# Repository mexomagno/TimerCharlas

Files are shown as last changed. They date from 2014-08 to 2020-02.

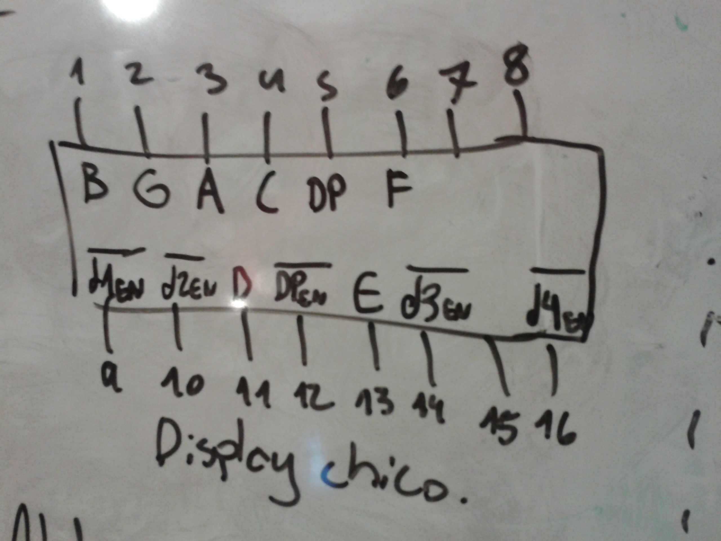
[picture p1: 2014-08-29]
Hardware/Componentes/camera/IMG_20140820_162948.jpg

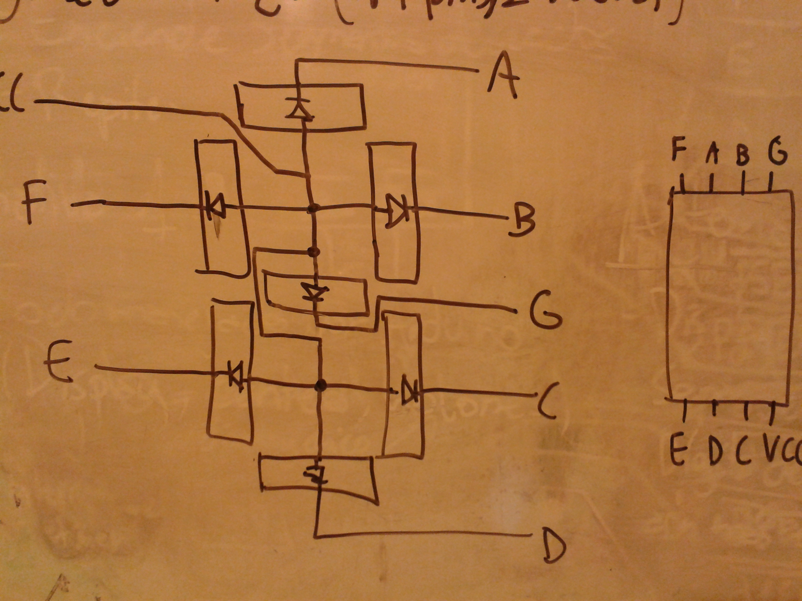
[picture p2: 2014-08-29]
Hardware/Componentes/camera/IMG_20140820_185731.jpg

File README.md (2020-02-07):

Timer para Charlas
============

<h3>Display de cuenta regresiva para charlas y presentaciones.</h3>
<p>Al momento de dar una charla, exponer en un seminario, hablar ante audiencias con tiempo limitado, llevar la cuenta del tiempo restante es esencial. Cuando el escenario es grande o es necesario moverse, es cómodo poder enterarse de cuánto tiempo queda a través de un estímulo visual.</p>
<p>El timer de charlas pretende ser un apoyo para las personas que tengan esta necesidad particular, y que no consideren suficientes las aplicaciones de tablets destinadas a este mismo fin, donde el tamaño del display depende del tamaño del tablet, además de ser poco discreto poner un tablet en el suelo.</p>
Este es un proyecto personal que no busca ser nada grande. Se dio por dos cosas:
<ol>
<li>Mi madre quería reemplazar un sistema de semáforo que tenían que era totalmente manual y poco práctico.</li>
<li>Es un desafío personal e involucra usar los distintos conocimientos ociosos que he ido adquiriendo sobre electrónica en general.</li>
</ol>
El concepto básico es (con el gentil auspicio de <i>ms-paint</i>) como sigue:


## Ve el resultado funcionando:

Ve el resultado del proyecto (https://www.youtube.com/watch?v=EdfVrNvKX3U)

<h4><i>Hardware</i></h4>
<p>Es un artefacto de aproximadamente 40x10 cm<sup>2</sup> de superficie y el grosor que tenga que tener, dependiendo de la circuitería.</p>
El diseño de las partes se encuentra documentado, así como los posibles brainstorms que les dan nacimiento.
<h4><i>Software</i></h4>
<p>El display es totalmente controlado por un Arduino Pro Mini. El manejo de los segmentos y del programa en sí del Timer de Charlas está implementado mediante el uso de interrupciones de dos de los tres timers internos del Atmega328 (el timer1 y el timer2), para así obtener toda la precisión que el cristal de cuarzo de 16 [MHz] puede ofrecer. </p>
<p>Si a alguien le es útil esto, por favor úselo.</p>

<h4><strong>Prestaciones implementadas</strong></h4>
<ul>
<li>Cuenta regresiva de tiempo de alta precisión, con tiempo máximo de 1:59:59 (un tiempo humanamente aceptable para una charla).</li>
<li>Luces tipo semáforo indicadoras rápidas del estado del tiempo restante.</li>
<li>Activación de luz amarilla y roja del semáforo ajustables.</li>
<li>Dígitos de 7 segmentos, 5 leds rojos de 5mm por cada segmento; correcto manejo de corrientes admitidas por cada dispositivo.</li>
<li>Transparencia en el código del programa principal, mediante la implementación de métodos de alto nivel que ocultan funcionalidades de bajo nivel.</li>
</ul>
<h4><strong>Posibles adiciones</strong></h4>
<ul>
<li>Interfaz por control remoto IR.</li>
<li>Permitir uso de batería.</li>
<li>Permitir el ajuste del brillo de los leds.</li>
</ul>

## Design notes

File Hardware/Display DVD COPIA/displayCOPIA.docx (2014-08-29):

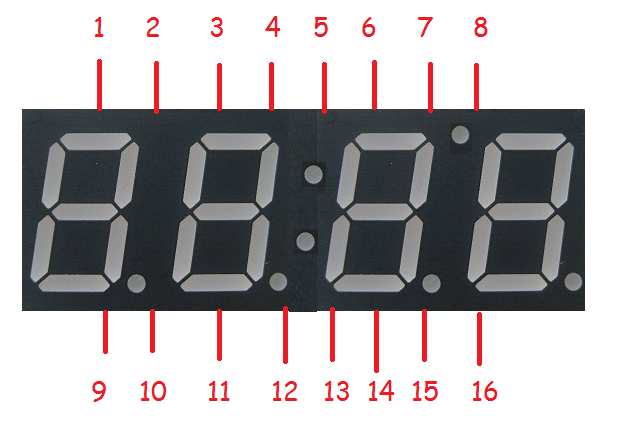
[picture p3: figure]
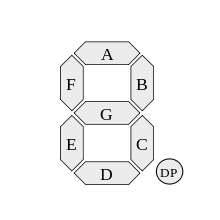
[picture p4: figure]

Pin | Función
~3 | Seg A
~1 | Seg B
~4 | Seg C
~11 | Seg D
~13 | Seg E
~6 | Seg F
~2 | Seg G
~15 | Seg DP
~5 | Dos puntos
~8 | Punto raro
9 | Digito 1
10 | Digito 2
14 | Digito 3
16 | Digito 4

GND en:

11)

9 prende D de digito 1

10 prende D de digito 2

14 prende D de digito 3

16 prende D de digito 4

13)

9 prende E de digito 1

10 prende E de digito 2

14 prende E de digito 3

16 prende E de digito 4

15)

9 prende DP de digito 1

10 prende DP de digito 2

14 prende DP de digito 3

16 prende DP de digito 4

1)

9,10,14,16 prenden B

2)

9, 10, 14, 16 prenden G

3) prenden A

4) prenden C

5) 12, prende los dos puntos centrales

6) prenden F

8) 7 prende punto raro

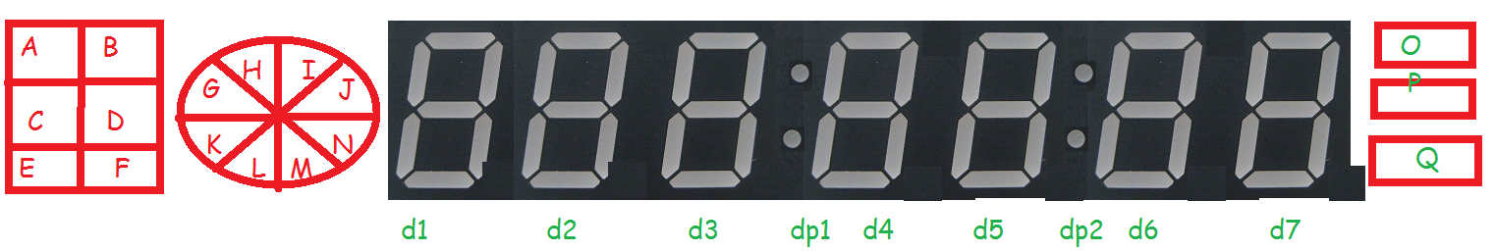
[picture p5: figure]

17 pins

GND en:

- 8 prende A
- 9 prende H
- 10 prende d3, A
- 11 prende d1, A
- 12 prende d2, A
- 13 prende d4, A
- 14 prende d5, A
- 15 prende d6, A
- 16 prende d7, A
- 17 prende O

En definitiva:

El recuadro con ABCDEF es “un digito”, que incluye al G. Equivalencias letra->segmento:

A →A, C→B, E→C, F→D, B→E, D→F, G→G

El disco HIJKLMN es otro “digito”.

H→A, I→B,L→C, M→D, K→E, J→F, N→G

El ultimo digito raro se compone de OPQ, DP1 y DP2. Equivalencias:

O→A, DP1→B, DP2→C, Q→D, P→E. FG no tienen función en este “dígito”.

Dado esto, se concluye que:

Pines de 1 al 7 deciden qué segmento prender. (1-7 prenden A-G)

Pines de 8 a 17 deciden qué dígito se activa (8-17 prenden digitos 1-10)

1 es recuadro izquierdo

2 es disco

3-9 son digitos normales

10 es ultimos leds (OPQ + DP1 DP2)

Ojo: Corriente fluye de pines 8-17 a pines 1-7.

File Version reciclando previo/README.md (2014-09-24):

Automatización Semáforo Existente
===============================
Este proyecto toma el semáforo básico existente y lo automatiza completamente. El semáforo anterior constaba sencillamente de un semáforo controlado con <strong>switches manuales</strong> que permitían encender cualquier luz.

La nueva versión permite programar el dispositivo, mediante interacción por botones y un display led.

----------------------
###**Componentes**
El control consta de tres botones:
>- SET
>- UP / START
>- DOWN / STOP

Además, posee un display numérico de 5 dígitos, que permite programar tiempos de hasta 2 horas.

Se cuenta con tres leds que simbolizan las luces del semáforo real.

Posee un conector de alimentación, y un conector al semáforo.

###**Instrucciones de uso**
Una vez encendido el dispositivo, debe esperar unos 5 segundos aproximadamente para que inicie (bootloader :( ).

####Configurar tiempo de cuenta regresiva
>Presione el botón **SET** para entrar al modo configuración. Los puntos comenzarán a parpadear. Esto indica que está seteando el primer dígito. Presione **UP/START** o **DOWN/STOP** para aumentar o disminuir este valor.

>Para configurar el siguiente dígito, presione nuevamente **SET**. El dígito seleccionado parpadeará. 

>Repita lo anterior para configurar todos los dígitos.

>Cuando llegue al último dígito, presionar **SET** termina la configuración.

####Iniciar, pausar y detener cuenta regresiva
>*Iniciar*

>Una vez configurado el tiempo de cuenta regresiva, presione **UP/START**. Durante la cuenta, el semáforo se encenderá de los siguientes colores:

> - Verde: Si quedan más de 5 minutos de cuenta.
> - Amarillo: Si quedan menos de 5 minutos de cuenta.
> - Rojo: Si el tiempo se ha terminado.

>*Pausar*

>Presione **UP/START** para pausar la cuenta regresiva. Los números se encenderán de manera intermitente. 

>*Detener*

>Presione **DOWN/STOP** para detener la cuenta regresiva. El contador retornará a cero y volverá a un estado equivalente a encender el dispositivo.

####Cambiar encendido de luz amarilla
>Por defecto, la luz amarilla se enciende cuando quedan 5 minutos de cuenta. Si usted desea cambiar este valor, debe seguir los siguientes pasos:

>En el estado de inicio del dispositivo, mantenga presionado **SET** por 2 segundos. Los puntos parpadearán, *junto con la luz amarilla del semáforo*. 
>El display mostrará el tiempo pre-configurado en el cual el semáforo se enciende de color amarillo. Cambie este valor a su voluntad.

>Finalice la configuración presionando **SET** hasta haber configurado cada dígito.

>La próxima vez que inicie la cuenta regresiva, el semáforo se encenderá de color amarillo cuando el tiempo restante sea el que usted ha configurado.

>*<strong>Importante</strong>: este valor <strong>no</strong> es almacenado al apagarse el dispositivo. Cuando lo apague y encienda nuevamente, volverá a estar configurado para encender la luz amarilla cuando queden 5 minutos restantes.*

>Si al mantener presionado **SET** el parpadeo de la luz amarilla del semáforo no sucede, no presionó el botón el tiempo suficiente y estará configurando el tiempo de cuenta regresiva. En este caso, para salir,  presione **SET** hasta haber recorrido todos los dígitos (5 veces).

---------
###Agradecimientos
NADIE.

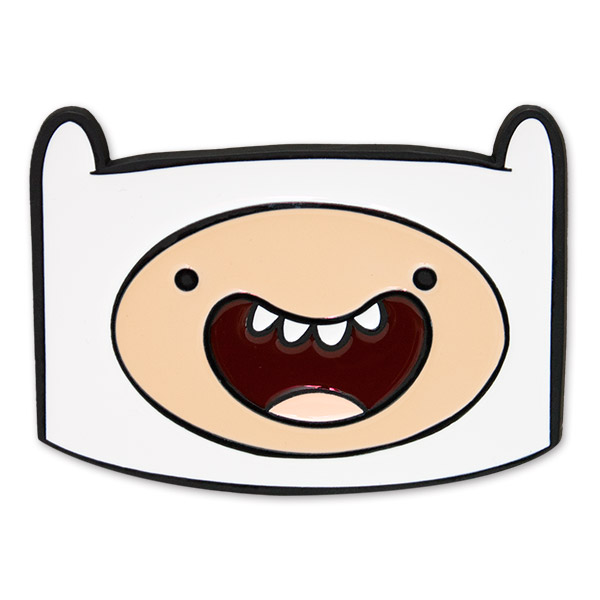
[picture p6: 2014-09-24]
Version reciclando previo/Hardware/finn.jpg

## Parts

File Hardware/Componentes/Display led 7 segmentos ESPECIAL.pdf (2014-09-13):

# Display led 7 segmentos ESPECIAL

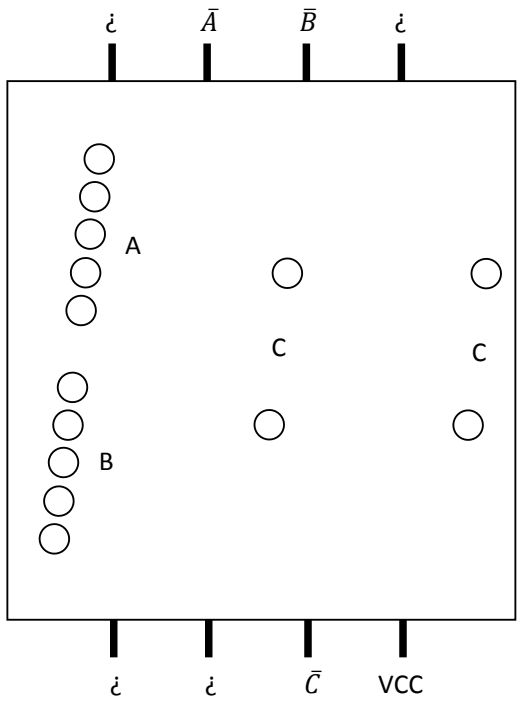
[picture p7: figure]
VCC

3 segmentos, 2 de 5 leds y 1 de 4 leds.

Ánodo común (VCC común, GND por separado).

Valores óptimos:

Voltaje: todos de 0 a 5V

Corriente A, B: 100mA cada segmento

Corriente C: 80mA

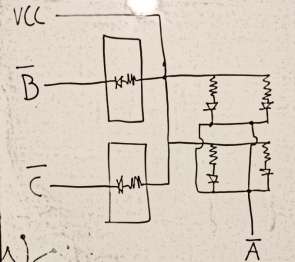
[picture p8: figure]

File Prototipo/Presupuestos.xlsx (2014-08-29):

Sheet: Alt 1
Alternativa 1: Construir todo desde cero
Cosas compradas hasta ahora
Item | Cantidad | Precio unidad | total | stock
Luz led | 200 | 28 | 5600 | Casa Keim
soldadura | 0 | 1600 | 0
pasta soldar | 0 | 890 | 0
resistencias | 500 | 7 | 3500 | Casa Keim
transistores npn | 30 | 70 | 2100 | victronics
Arduino Pro Mini | 1 | 6980 | 6980 | Rambal
regulador voltaje | 1 | 210 | 210 | victronics
cristal oscilador 16MHz | 0 | 298 | 0 | victronics
capacitores | 30 | 10 | 300 | casa
Placa cobre circuito | 0 | 3200 | 0 | victronics
Cloruro férrico | 0 |  | 0
plug batería | 0 | 756 | 0 | olimex
batería | 0 | 3000 | 0
plug transformador | 0 | 100 | 0
Hardware varios | 0 | 4000 | 0
transformador | 0 | 0 | 0
 |  | TOTAL | 18690

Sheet: Alt 2
Alternativa 2: módulos específicos
Categoría | Item | Cantidad | Precio unidad | total | Link
Módulos | Display 1.2'' | 1 | 12466 | 12466 | http://www.olimex.cl/product_info.php?products_id=1410&product__name=Display_1.2
 | Arduino pro-mini | 1 | 11503 | 11503 | http://www.olimex.cl/product_info.php?products_id=930&product__name=Arduino_Pro_Mini_328_5V_16MHz
 | FTDI | 1 | 11297 | 11297 | http://www.olimex.cl/product_info.php?products_id=580&product__name=FTDI_Basic_Breakout_3.3V_5V
Comp. Electrónicos | capacitores | 30 | 20 | 600
 | Regulador voltaje | 1 | 500 | 500
 | resistencias | 30 |  | 0
 | transistores npn | 30 |  | 0
Herramientas y materiales | Placa cobre circuito | 2 |  | 0
 | Cloruro férrico | 1 |  | 0
 | soldadura | 1 | 1600 | 1600
 | pasta soldar | 1 | 890 | 890
 |  |  |  | 0
 |  |  |  | 0
 |  |  |  | 0
 |  |  |  | 0
 | plug batería |  |  | 0
 | batería |  |  | 0
 | plug transformador |  |  | 0
 | transformador

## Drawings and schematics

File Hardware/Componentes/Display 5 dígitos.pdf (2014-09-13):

# Display led 5 dígitos

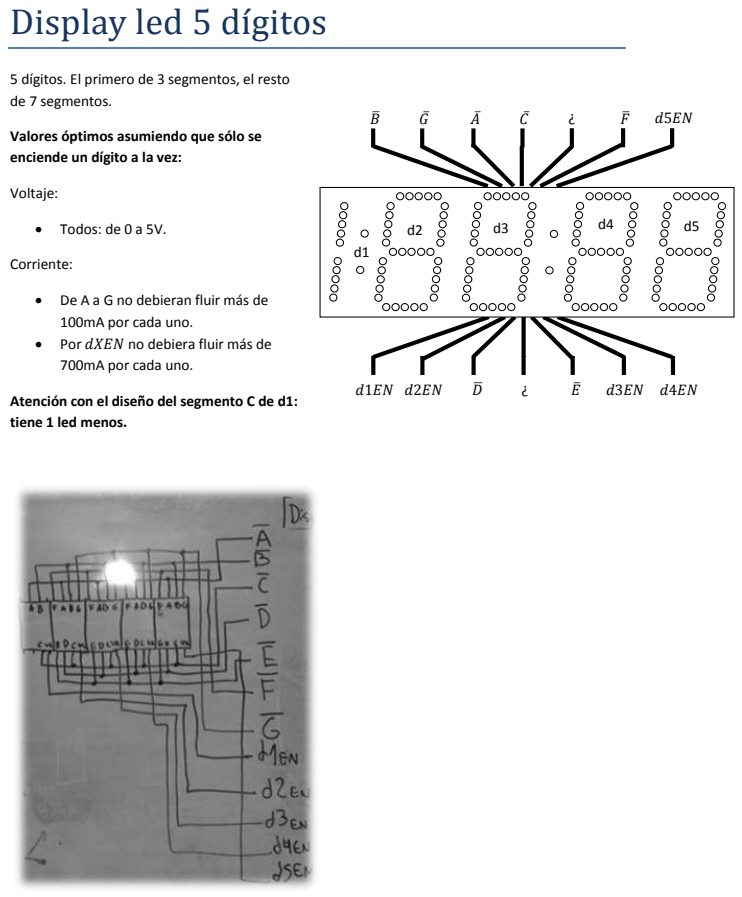
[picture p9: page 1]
Voltaje:; • Todos: de 0 a 5V.; Corriente:; Por; no debiera fluir más de

5 dígitos. El primero de 3 segmentos, el resto
de 7 segmentos.

Valores óptimos asumiendo que sólo se
enciende un dígito a la vez:

• De A a G no debieran fluir más de
100mA por cada uno.
700mA por cada uno.

Atención con el diseño del segmento C de d1:
tiene 1 led menos.

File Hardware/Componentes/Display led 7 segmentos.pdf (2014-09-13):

# Display led 7 segmentos

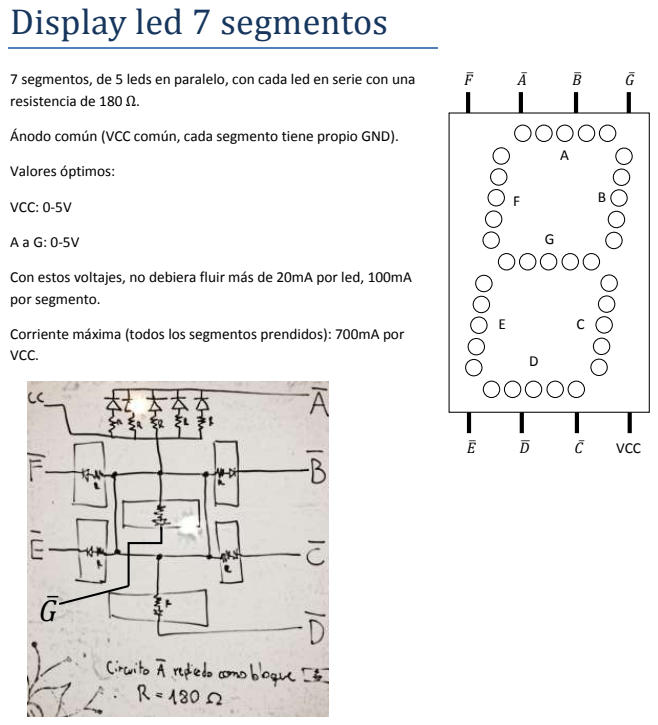
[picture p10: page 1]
Valores óptimos:; VCC: 0-5V; VCC

7 segmentos, de 5 leds en paralelo, con cada led en serie con una
resistencia de 180 .

Ánodo común (VCC común, cada segmento tiene propio GND).

Con estos voltajes, no debiera fluir más de 20mA por led, 100mA
por segmento.

Corriente máxima (todos los segmentos prendidos): 700mA por
VCC.

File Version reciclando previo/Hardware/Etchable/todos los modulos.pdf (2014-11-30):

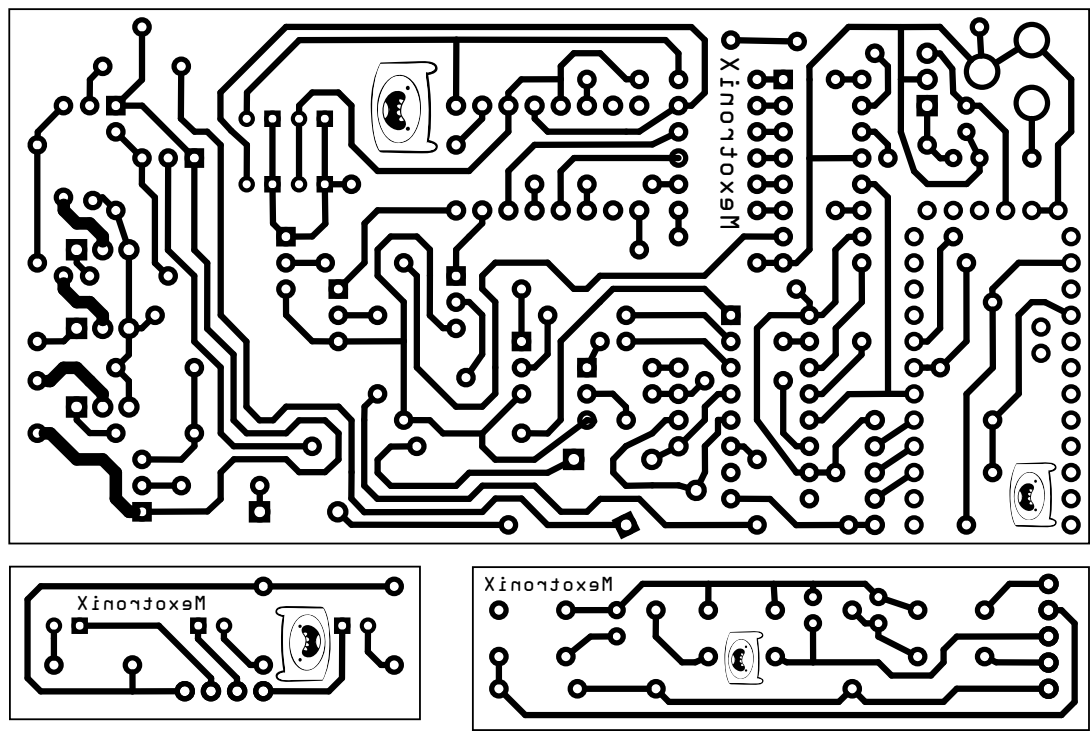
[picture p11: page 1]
MexotroniX

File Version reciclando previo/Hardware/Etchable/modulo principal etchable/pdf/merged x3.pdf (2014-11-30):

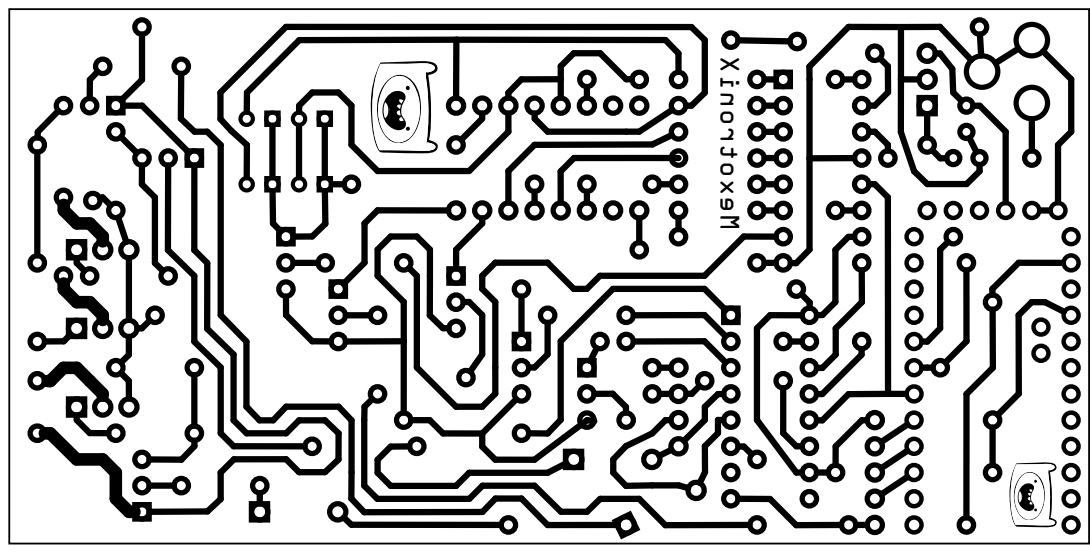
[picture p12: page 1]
MexotroniX

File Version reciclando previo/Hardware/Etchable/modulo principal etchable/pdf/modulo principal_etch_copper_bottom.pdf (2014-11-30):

MexotroniX

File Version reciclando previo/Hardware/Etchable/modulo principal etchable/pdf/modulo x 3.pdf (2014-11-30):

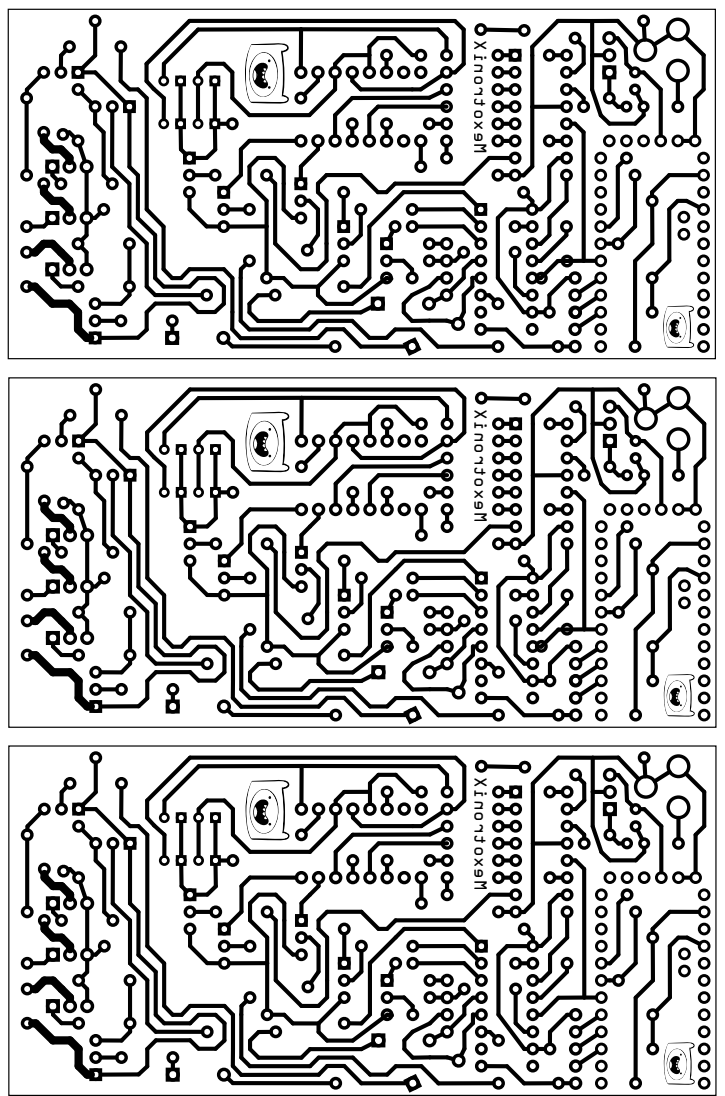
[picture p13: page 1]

MexotroniX MexotroniX MexotroniX

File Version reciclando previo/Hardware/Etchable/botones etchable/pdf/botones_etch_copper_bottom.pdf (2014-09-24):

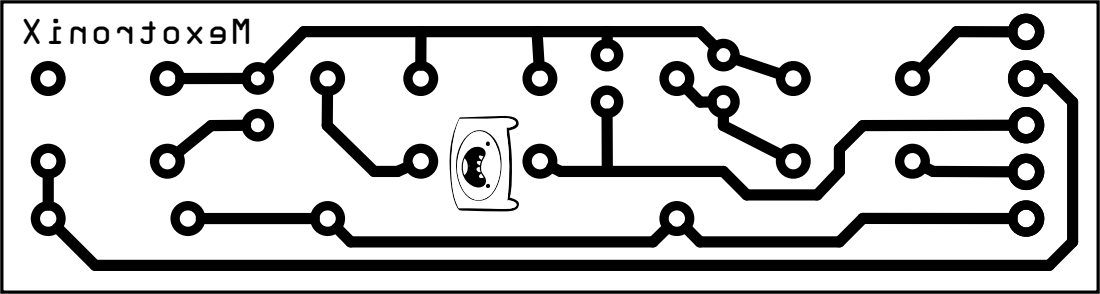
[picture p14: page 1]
MexotroniX

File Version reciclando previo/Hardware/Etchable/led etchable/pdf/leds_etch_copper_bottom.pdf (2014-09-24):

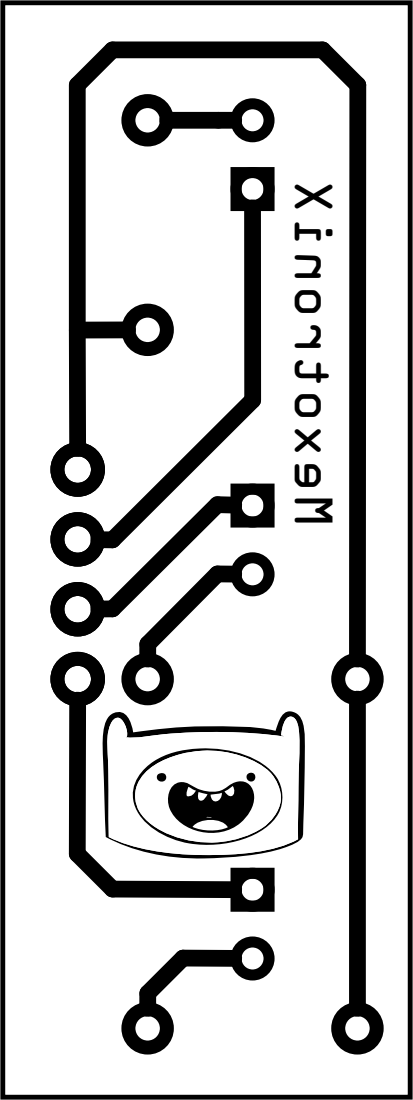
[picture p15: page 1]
MexotroniX

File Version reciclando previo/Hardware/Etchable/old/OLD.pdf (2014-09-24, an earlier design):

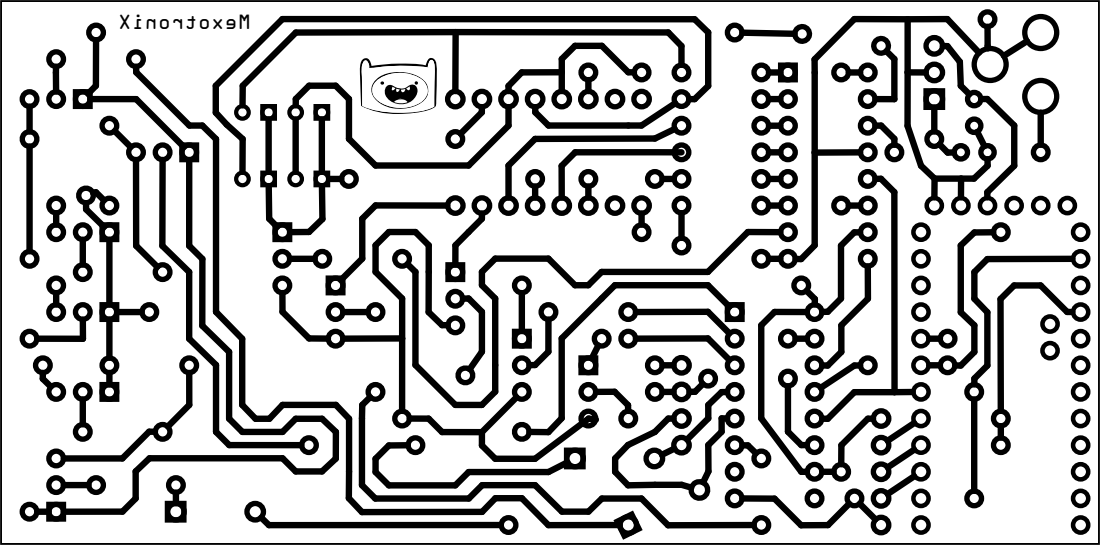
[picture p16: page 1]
MexotroniX

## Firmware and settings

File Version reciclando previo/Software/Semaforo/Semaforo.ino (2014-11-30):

/* SETUP:
        Se trabaja mediante 2 shift registers
        -Pin 2 a SER
        -Pin 3 a RCLK
        -Pin 4 a SRCLK
       
        3 botones configuran
        -Pin 5 boton SET
        -Pin 6 boton UP/START
        -Pin 7 boton DOWN/STOP
        Usar capacitores para debounce
        
*/
/************ CONSTANTES ************/
typedef enum{
  IDLE,
  H1,
  M1,
  M2,
  S1,
  S2,
  RUN,
  PAUSE
}STATE;
/************ VARIABLES *************/
STATE state;
/************ METODOS ***************/
#define getBit(w,n) ((w&(1<<n))>>n)
#define setBit(w,n) (w|(1<<n))
#define clrBit(w,n) (w&~(1<<n))
#define writeBit(w,n,b) (b ? setBit(w,n) : clrBit(w,n))
void initProgram(){
  initBotones();
  initDisplay(2,3,4);
  state=IDLE;
  timerStop();
  setTime(0,0,0);
  triggerAmarilla(0,5,0);
  triggerRoja(0,0,0);
}
long t0,t1;
void setup(){
  initProgram();
  pinMode(13,OUTPUT);
}
void loop(){
  checkBotones();
}

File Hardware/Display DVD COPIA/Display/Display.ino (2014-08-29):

/* Setup:
    */
char pins[]={2,3,4,5};
char shiftpin=6;
//char digit=0; //0: menos significativo.

char number=0;
/*long t0=millis();
long t1;*/

void initTimer2(){
  /* Desactivar interrupciones por overflow del contador*/
  TIMSK2  &= ~(1<<TOIE2);
  /* Activar interrupciones por Compare Match A*/
  TIMSK2 |= (1<<OCIE2A);
  /* Limpiar registros TCCR2A y TCCR2B*/
  TCCR2A = 0;
  TCCR2B = 0;
  /* Setear modo CTC (Clear Timer on Compare match): se resetea
  automáticamente el timer al igualarse al valor OCR2A por fijar*/
  TCCR2A |= (1<<WGM21);
  /* Configurar el prescaler a 1024. Con eso basta*/
  TCCR2B |= (1<<CS20);
  TCCR2B |= (1<<CS21);
  TCCR2B |= (1<<CS22);
  /* Setear el valor para el cual se generará una interrupción. con 128, se genera una interrupción cada 8,192 ms*/
  OCR2A=170;
}

ISR(TIMER2_COMPA_vect){
  /* se debe cambiar el display activo*/
  PORTD ^= 1 << shiftpin;
  PORTD &= B11000011;
  PORTD |= ((PORTD&B01000000? number/10 : number%10)<<pins[0]);
  //digit=~digit;//PORTD&(1<<shiftpin);
}

void setup(){
  for (int i=0;i<4; i++){
    pinMode(pins[i], OUTPUT);
  }
  pinMode(shiftpin,OUTPUT);
  //digitalWrite(shiftpin,HIGH);
  /* setea timer 2 para turnar displays*/
  cli();
  initTimer2();
  sei();
}
/*void setNum(char numero){
  number=numero
}*/
void loop(){
  //setNum(number);
  //delay(100);
  //number= number==99? 0 : number+1;
  /*t1=millis();
  if (t1-t0>=1000){
    number= number==9? 0 : number+1;
    setNum(number);
    t0=millis()-(t1-t0-1000);
  }*/
}

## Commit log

2014-08-29 Archivos añadidos
    Se agregan todos los archivos locales
    [Display.fzz, Presupuestos.xlsx]
2014-09-13 Gran Actualización
    -Agregados botones y sus funcionalidades
    -Fijados estados del timer
    -refactoring general
    [Control puramente pcb.fzz, Display.fzz, display especial puramente pcb.fzz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]
2014-09-24 Actualización hardware y software
    Hardware:
    -Edición de módulo principal para caber en la cajita
    -Edición de módulos para agregar logo y carita
    Software:
    -Añadida funcionalidad de programación de activación de la luz amarilla
    [botones.fzz, leds.fzz, modulo principal.fzz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]
2014-09-24 Reordenar directorios y añadir manual
    -Directorios reestructurados para mejorar entendimiento
    -Se agrega manual del usuario en el README del proyecto
    [botones.fzz, leds.fzz, modulo principal.fzz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]
2014-11-30 Commit para borrado de datos por nuevo computador
    [botones.fzz, leds.fzz, modulo principal.fzz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]
